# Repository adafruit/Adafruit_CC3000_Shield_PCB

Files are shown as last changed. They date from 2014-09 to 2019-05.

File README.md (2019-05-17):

# Adafruit CC3000 Shield PCB
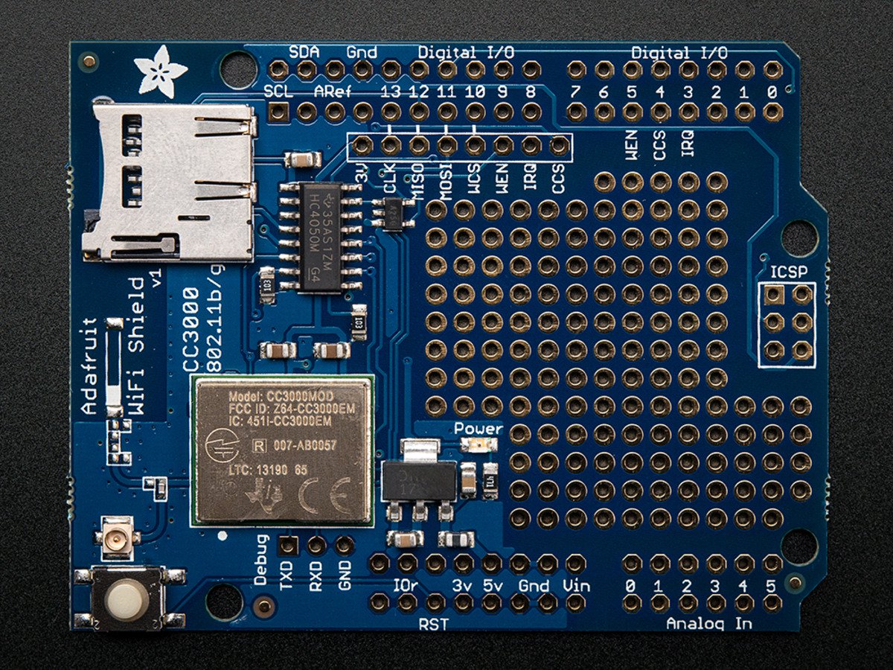
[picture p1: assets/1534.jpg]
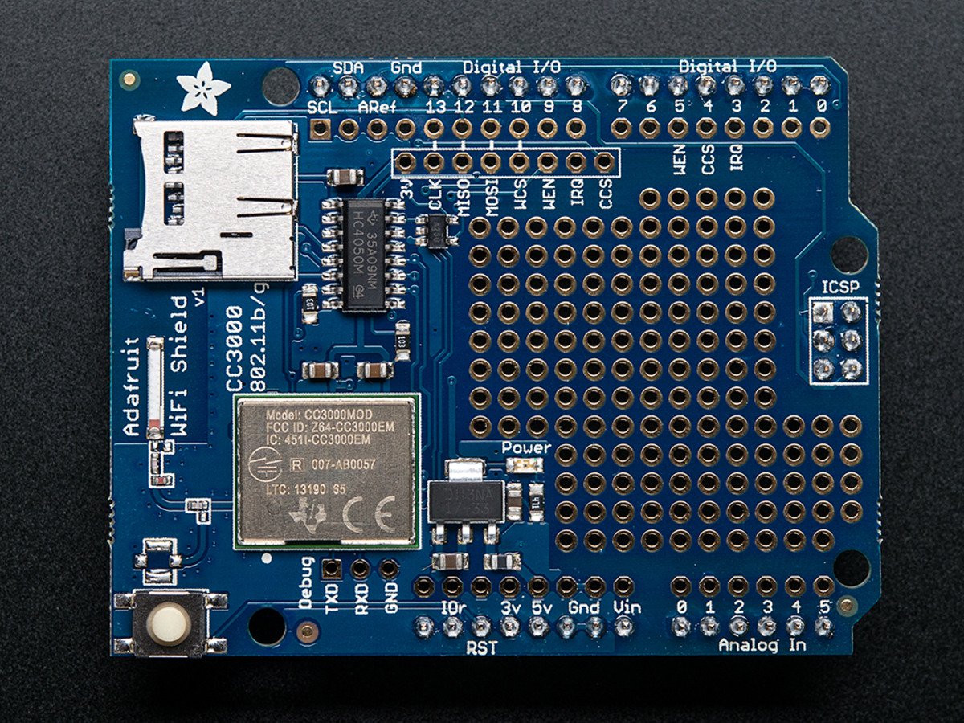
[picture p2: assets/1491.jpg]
&nbsp; <br />
Click to view in the Adafruit Shop:
- [Adafruit CC3000 WiFi Shield with uFL Connector for Ext Antenna (DISCONTINUED)](https://www.adafruit.com/product/1534)
- [Adafruit HUZZAH CC3000 WiFi Shield with Onboard Antenna (DISCONTINUED)](https://www.adafruit.com/product/1491)

The CC3000 hits that sweet spot of usability, price and capability. It uses SPI for communication (not UART!) so you can push data as fast as you want or as slow as you want. It has a proper interrupt system with IRQ pin so you can have asynchronous connections. It supports 802.11b/g, open/WEP/WPA/WPA2 security, TKIP & AES. A built in TCP/IP stack with a "BSD socket" interface. TCP and UDP in both client and server mode, up to 4 concurrent sockets. It does not support "AP" mode, it can connect to an access point but it cannot be an access point.

**Please note that the CC3000 module is discontinued and we suggest the [Adafruit Airlift products](https://www.adafruit.com/?q=airlift) as a replacement** - it has SSL support, soft-AP capability, and is more reliable.

PCB files for Adafruit CC3000 Shields. The format is EagleCAD schematic and board layout

For more details, check out the product page at

-----> http://www.adafruit.com/products/1534
-----> http://www.adafruit.com/products/1491

### License

Adafruit invests time and resources providing this open source design, please support Adafruit and open-source hardware by [purchasing products from Adafruit](https://www.adafruit.com)!

All text above must be included in any redistribution

Designed by Limor Fried/Ladyada for Adafruit Industries.
Creative Commons Attribution/Share-Alike, all text above must be included in any redistribution. 
See license.txt for additional information.

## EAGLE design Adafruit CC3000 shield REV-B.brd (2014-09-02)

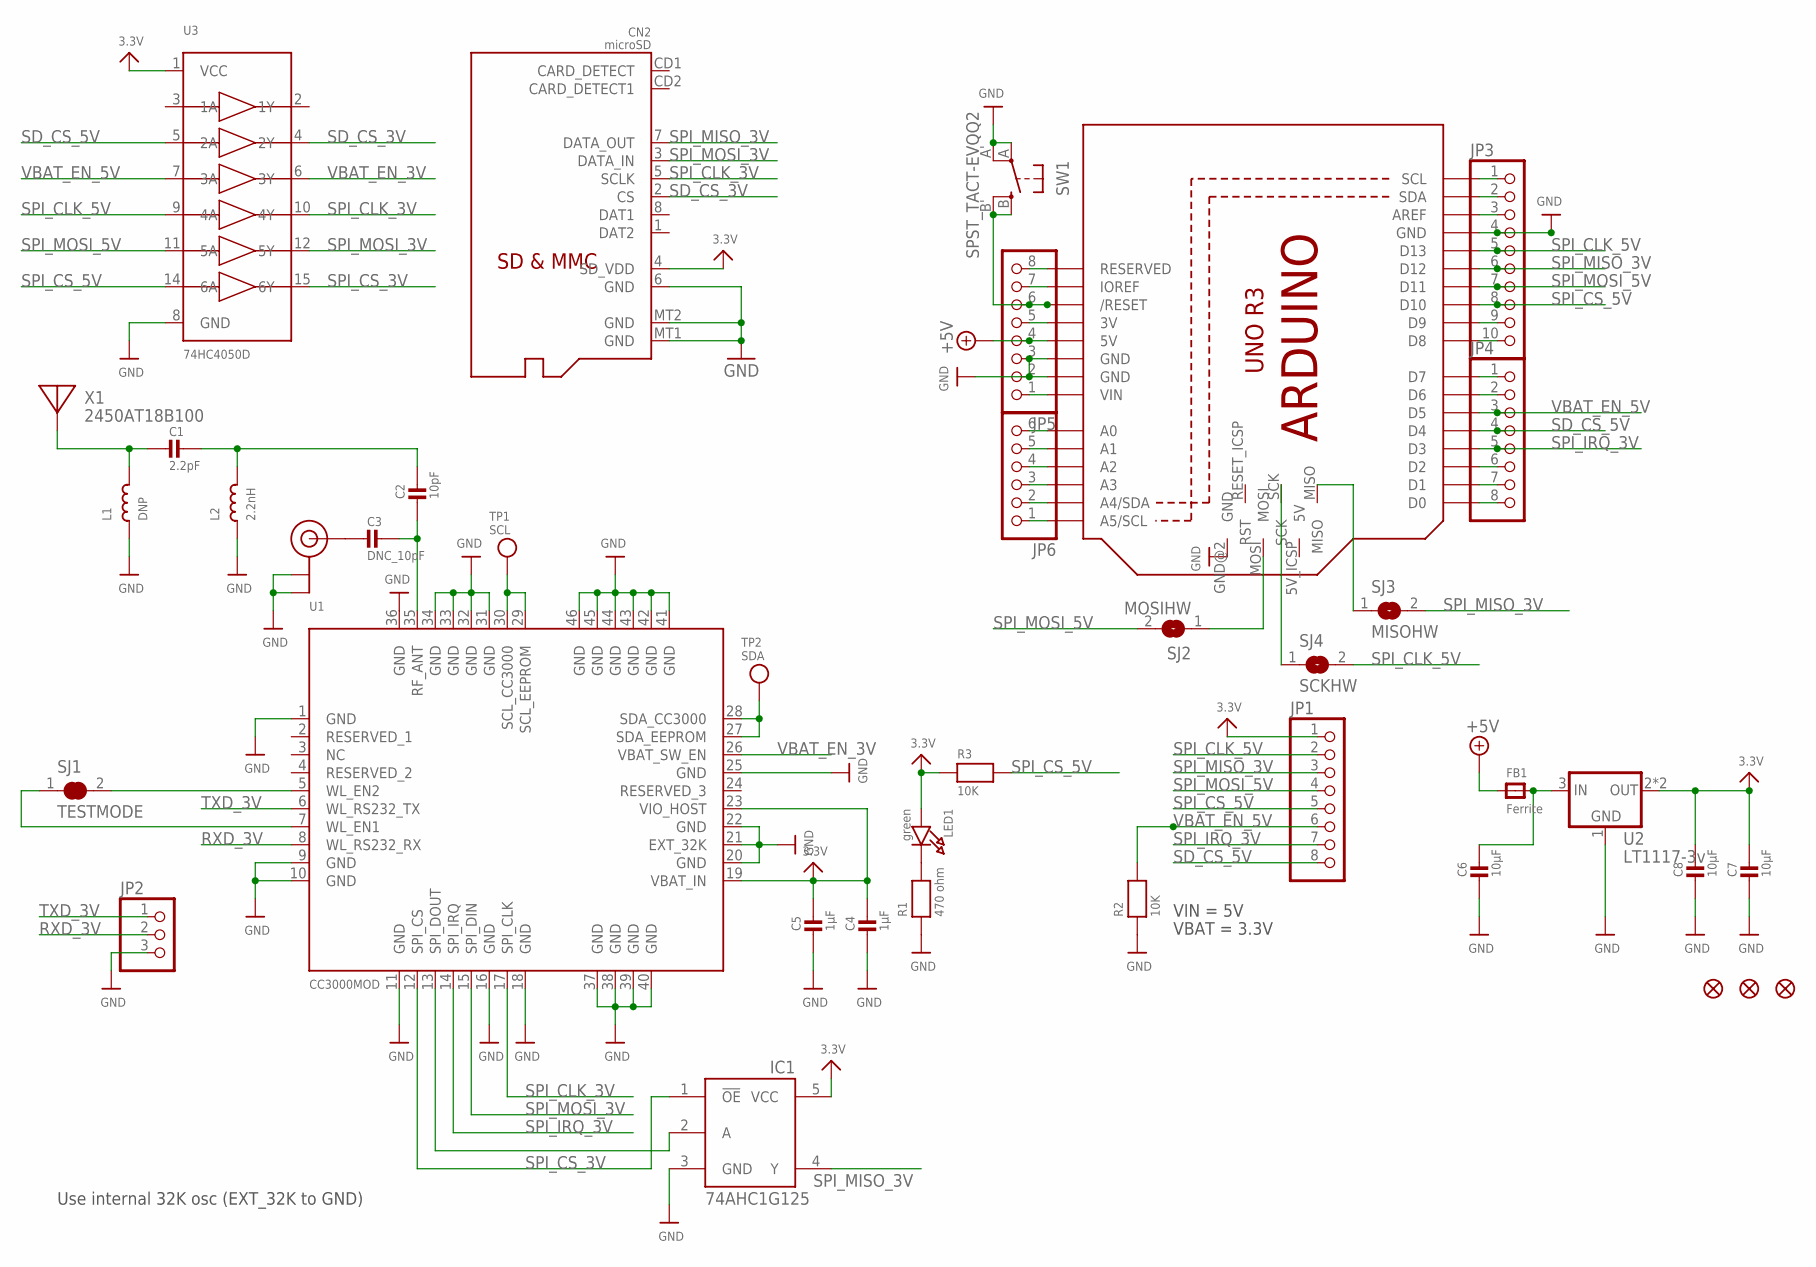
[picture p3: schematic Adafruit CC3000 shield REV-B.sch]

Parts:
C1: 2.2pF; _0402
C2: 10pF; _0402
C3: DNC_10pF; _0402
C4, C5: 1µF; _0805MP
C6, C7, C8: 10µF; _0805MP
CN2: microSD; MICROSD
FB1: Ferrite; _0805MP
FID1, FID2, FID3: FIDUCIAL""; FIDUCIAL_1MM
IC1: 74AHC1G125; SOT23-5L
JP1: PINHD-1X8BIG; 1X08-BIG
JP2: HEADER-1X3ROUND; 1X03_ROUND
JP3: HEADER-1X1070MIL; 1X10_ROUND70
JP4, JP5: PINHD-1X8CLEANBIG; 1X08-CLEANBIG
JP6: PINHD-1X6CB; 1X06-CLEANBIG
L1: DNP; _0402
L2: 2.2nH; _0402
LED1: green; CHIPLED_0805_NOOUTLINE
R1: 470 ohm; _0805MP
R2, R3: 10K; _0805MP
SJ1: TESTMODE; SOLDERJUMPER_CLOSEDWIRE
SJ2: MOSIHW; SOLDERJUMPER_ARROW_NOPASTE
SJ3: MISOHW; SOLDERJUMPER_ARROW_NOPASTE
SJ4: SCKHW; SOLDERJUMPER_ARROW_NOPASTE
SW1: SPST_TACT-EVQQ2; EVQ-Q2
TP1: SCL; TESTPOINT_PAD_1MM
TP2: SDA; TESTPOINT_PAD_1MM
U1: CC3000MOD
U2: LT1117-3v; SOT223-R
U3: 74HC4050D; SOIC16
U$35: U.FL
U$36: ARDUINO_R3_ICSP; ARDUINOR3_ICSP
X1: 2450AT18B100; ANT_2500AT44M0400

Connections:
3.3V: C4.1, C5.1, C7.1, C8.1, CN2.4 (SD_VDD), IC1.5 (VCC), JP1.1, LED1.A, R3.1, U1.19 (VBAT_IN), U1.23 (VIO_HOST), U2.2 (OUT), U2.4 (OUT), U3.1 (VCC)
+5V: FB1.1, JP5.4, U$36.5V
GND: C4.2, C5.2, C6.2, C7.2, C8.2, CN2.6 (GND), CN2.MT1 (GND), CN2.MT2 (GND), IC1.3 (GND), JP2.3, JP3.4, JP5.2, JP5.3, L1.1, L2.1, R1.1, R2.1, SW1.A, SW1.A' (P1), U1.1 (GND), U1.9 (GND), U1.10 (GND), U1.11 (GND), U1.16 (GND), U1.18 (GND), U1.20 (GND), U1.21 (EXT_32K), U1.22 (GND), U1.25 (GND), U1.31 (GND), U1.32 (GND), U1.33 (GND), U1.34 (GND), U1.36 (GND), U1.37 (GND), U1.38 (GND), U1.39 (GND), U1.40 (GND), U1.41 (GND), U1.42 (GND), U1.43 (GND), U1.44 (GND), U1.45 (GND), U1.46 (GND), U2.1 (GND), U3.8 (GND), U$35.P$1 (GND), U$35.P$2 (GND), U$36.GND, U$36.GND@1 (GND), U$36.GND@2 (GND), U$36.GND@3 (GND)
unnamed: C1.2, L1.2, X1.FEED
unnamed: C1.1, C2.1, L2.2
unnamed: C3.2, U$35.P$3 (SIGNAL)
unnamed: C2.2, C3.1, U1.35 (RF_ANT)
unnamed: SJ1.2, U1.5 (WL_EN2)
unnamed: SJ1.1, U1.7 (WL_EN1)
unnamed: JP3.1, U$36.SCL
unnamed: JP3.2, U$36.SDA
unnamed: C6.1, FB1.2, U2.3 (IN)
unnamed: JP3.3, U$36.AREF
unnamed: JP5.6, SW1.B (S), SW1.B' (S1), U$36.RESET (/RESET)
unnamed: IC1.2 (A), U1.13 (SPI_DOUT)
unnamed: JP3.9, U$36.D9
unnamed: JP3.10, U$36.D8
unnamed: JP4.1, U$36.D7
unnamed: JP4.2, U$36.D6
unnamed: JP4.6, U$36.D2
unnamed: JP4.7, U$36.D1
unnamed: JP4.8, U$36.D0
unnamed: JP5.1, U$36.VIN
unnamed: JP5.5, U$36.3V
unnamed: JP5.7, U$36.IOREF
unnamed: JP5.8, U$36.RESERVED
unnamed: JP6.1, U$36.A5 (A5/SCL)
unnamed: JP6.2, U$36.A4 (A4/SDA)
unnamed: JP6.3, U$36.A3
unnamed: JP6.4, U$36.A2
unnamed: JP6.5, U$36.A1
unnamed: JP6.6, U$36.A0
unnamed: LED1.C, R1.2
unnamed: SJ2.1, U$36.MOSI
unnamed: SJ4.1, U$36.SCK
unnamed: SJ3.1, U$36.MISO
RXD_3V: JP2.2, U1.8 (WL_RS232_RX)
SCL_3V: TP1.P$1, U1.29 (SCL_EEPROM), U1.30 (SCL_CC3000)
SDA_3V: TP2.P$1, U1.27 (SDA_EEPROM), U1.28 (SDA_CC3000)
SD_CS_3V: CN2.2 (CS), U3.4 (2Y)
SD_CS_5V: JP1.8, JP4.4, U3.5 (2A), U$36.D4
SPI_CLK_3V: CN2.5 (SCLK), U1.17 (SPI_CLK), U3.10 (4Y)
SPI_CLK_5V: JP1.2, JP3.5, SJ4.2, U3.9 (4A), U$36.D13
SPI_CS_3V: IC1.1 (!OE), U1.12 (SPI_CS), U3.15 (6Y)
SPI_CS_5V: JP1.5, JP3.8, R3.2, U3.14 (6A), U$36.D10
SPI_IRQ_3V: JP1.7, JP4.5, U1.14 (SPI_IRQ), U$36.D3
SPI_MISO_3V: CN2.7 (DATA_OUT), IC1.4 (Y), JP1.3, JP3.6, SJ3.2, U$36.D12
SPI_MOSI_3V: CN2.3 (DATA_IN), U1.15 (SPI_DIN), U3.12 (5Y)
SPI_MOSI_5V: JP1.4, JP3.7, SJ2.2, U3.11 (5A), U$36.D11
TXD_3V: JP2.1, U1.6 (WL_RS232_TX)
VBAT_EN_3V: U1.26 (VBAT_SW_EN), U3.6 (3Y)
VBAT_EN_5V: JP1.6, JP4.3, R2.2, U3.7 (3A), U$36.D5

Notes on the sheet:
Use internal 32K osc (EXT_32K to GND)
VIN = 5V
VBAT = 3.3V

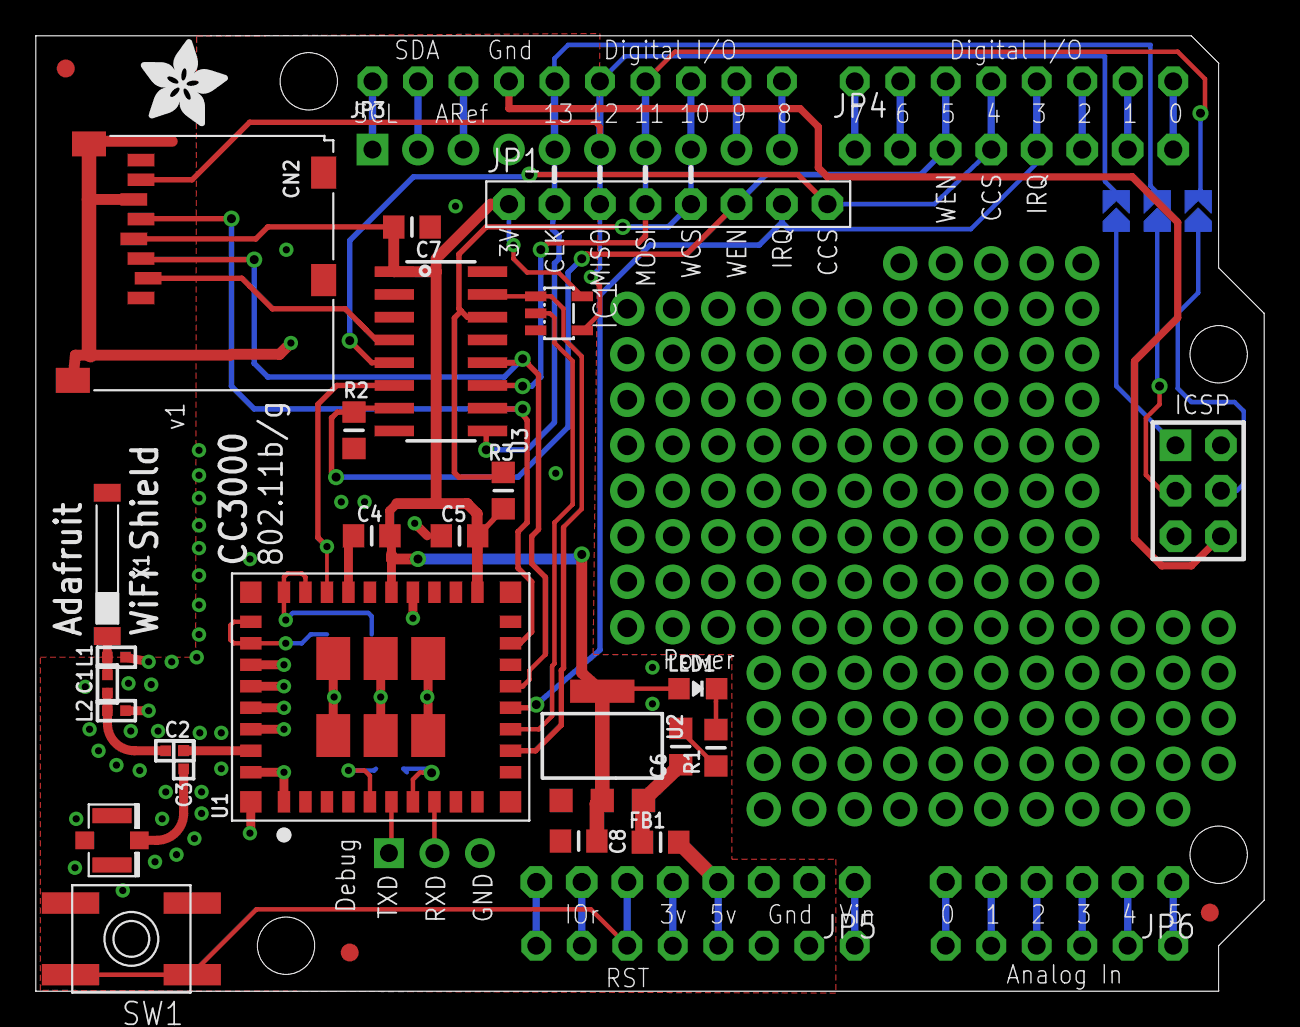
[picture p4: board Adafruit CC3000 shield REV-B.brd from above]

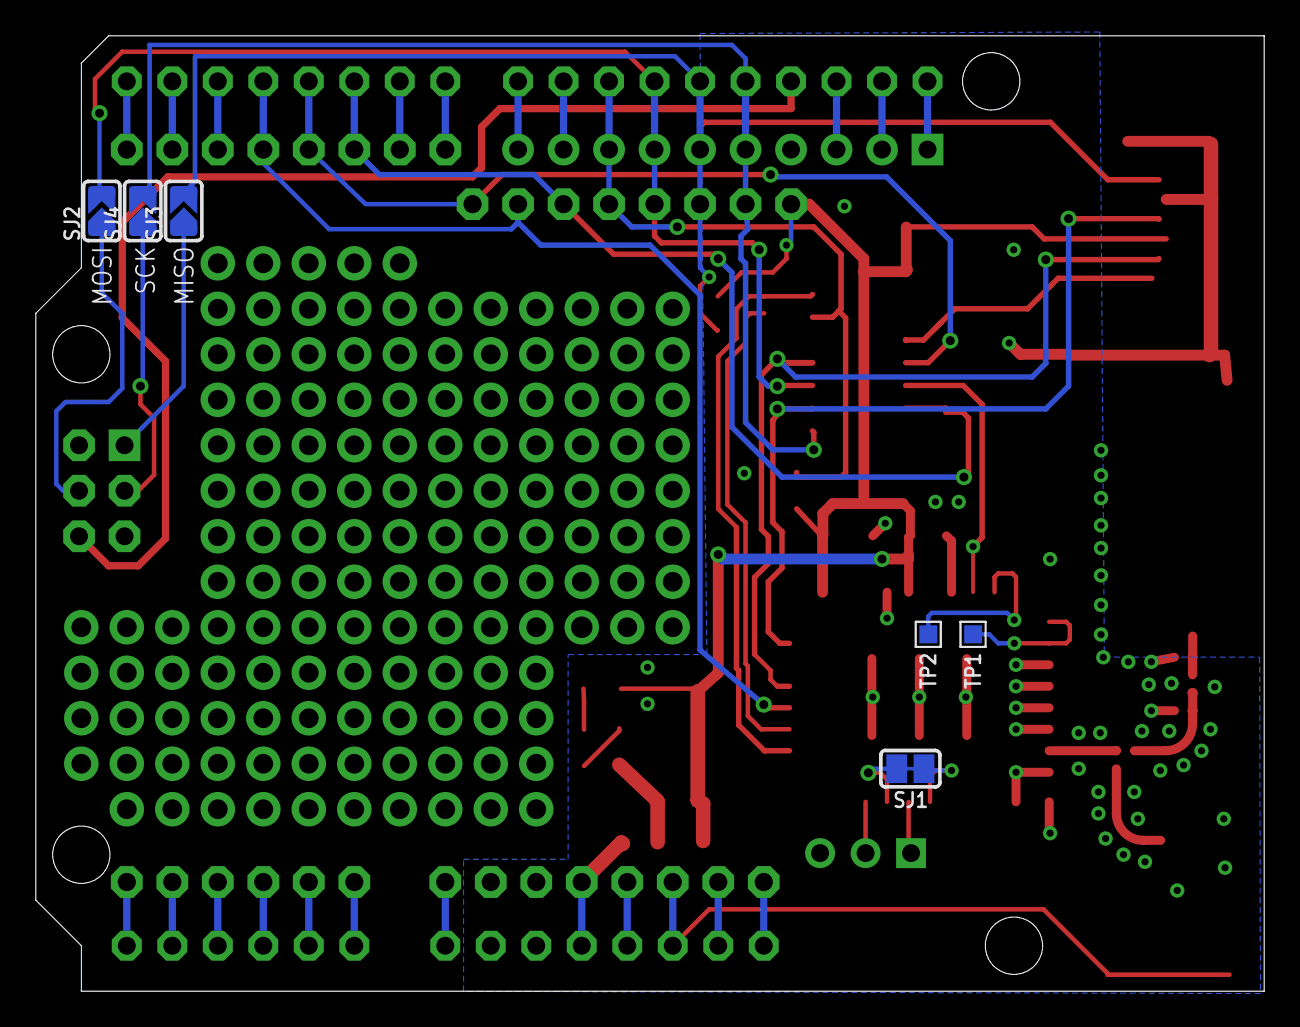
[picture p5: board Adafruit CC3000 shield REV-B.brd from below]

Board: 2 copper layers, 68.6 x 53.3 mm, 40 parts (6 on the bottom side), 52 nets.

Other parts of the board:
U$8: ADAFRUIT_5MM

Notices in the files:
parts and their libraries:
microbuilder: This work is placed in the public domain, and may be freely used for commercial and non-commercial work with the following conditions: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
